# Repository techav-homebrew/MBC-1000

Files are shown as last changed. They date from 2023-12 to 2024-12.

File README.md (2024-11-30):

# MBC-1000
Reverse-engineering notes &amp; documentation of the Sanyo MBC-1000 computer

## Jumpers

There are four undocumented jumpers on the board. 

- JP1
  - Open by default.
- JP2
  - Open by default.
- JP3
  - Bridged by default. Connects ROM pin 21 to Vcc.
- JP4
  - Open by default. Connects ROM pin 21 to buffered A11 signal. 
- JP5
  - Bridged by default. 

If the trace shorting JP3 is cut and a jumper inserted into JP4, then the board should support a 2732 (4kB) EPROM in place of the 2716 (2kB) EPROM. The system memory map when the startup ROM overlay is enabled does support a 4kB EPROM.

## Address Map

The Spanish manual appendix IV seems to suggest that the startup overlay is disabled when the system addresses an OP code at a memory address above `$8000`. 

### Startup Memory Space Map

| Address | Function |
| :--- | :--- |
| `$0000 - $07ff` | First 2716 Boot ROM | 
| `$0800 - $0fff` | Second 2716 / First 2732 |
| `$1000 - $7fff` | Allocated ROM Space | 
| `$8000 - $ffff` | Allocated RAM Space |

### Runtime Memory Space Map

| Address | Function | 
| :--- | :---: |
| `$0000 - $ffff` | RAM |

### I/O Space Map

| Address | Function | IC |
| :--- | :--- | :--- |
| `$E0` | Parallel Printer Port Controls for RDY/BUSY | -- |
| `$E4` | Floppy Disk Controller | MB8876A |
| `$E8` | Parallel Port Interface | NEC D8255AC-5 |
| `$EC` | CRT Controller | HD46505SP-2 (68B45) |
| `$F0 - $F4` | Character Generator | -- |
| `$F8 - $FC` | Video RAM for Screen | -- |

A disassembled BIOS has IO calls to devices in the `$C0 - $C4` range in some of the disk read & write functions. The motherboard IO devices are decoded by a 74LS138 enabled when A7, A6, and A5 are all high, so a device on `$C0` would not be selected by that chip. The serial expansion card can only be configured at `$A0`, `$A8`, `$B0`, or `$B8`, so it's not what is being addressed here either. The manual only references the on-board peripherals in the `$E0 - $F0` range. So far I have not been able to trace out anything on the motherboard that would be selected for IO addresses `$C0 - $C4`

#### I/O Device Registers

##### PPI 8255

- `$E8` - PPI Port A
- `$E9` - PPI Port B
- `$EA` - PPI Port C
- `$EB` - PPI Control Register

##### FDC 8879

- `$E4` - Status (RO) / Command (WO)
- `$E5` - Track
- `$E6` - Sector
- `$E7` - Data

##### CRTC 6845

- `$EC` - Address Register
- `$ED` - Settings Registers
- `$EE` - Light Pen Registers

## Floppy Drive Interface

MBC-1000 and its dual floppy expansion box, EFD-360, use YE Data YD-274 floppy drives. These are standard Shugart-interface double-sided double-density 5.25" drives.

The `HM` jumper is set on each drive, and drives are selected with the `DSx` jumpers (Drive A is `DS0`, Drive B is `DS1`, Drive C is `DS2`). The last drive in the chain (Drive A if EFD-360 not used, or Drive C at the top of the EFD-360 if used) must have the 150-Ohm terminating resistor block installed. 

Drives use standard 34-contact card edge connectors for data & control. The motherboard uses a corresponding latching 34-pin header. A Centronics CN36 connector is used for the external interface on both the computer and the expansion drive. Wires 35 & 36 on the CN36 are cut, leaving the remaining standard 34 ribbon cable wires.

BIOS has data tables for 8" drives, and contemporary advertisements listed an 8" drive option. Some advertisements & reviews also mentioned Winchester hard drive options. ( [CPM Review Nov 1982](https://ia802805.us.archive.org/23/items/198211CPMReview/198211%20CPM%20Review.pdf) ).

Since the computer uses standard Shugart interface for floppy drives, it is compatible with Gotek emulators without any additional hardware (tested using FlashFloppy firmware).

## Monitor

The monitor is an NEC green phosphor display, type number C1270P1H-ARG. Its analog drive board is labeled with the Sanyo logo and `PH 50-002` & `PH-50E`.

## Escape Codes

Appendix VI of the Spanish manual provides an escape code sequence for positioning the cursor on screen:

> Las coordenadas X e Y tienen un umbral de valor hexa 20. Por ejemplo, para poner el cursor en la posicion X = 6 e Y = 8: 1Bh (ESC), 3Dh (=) 28h (20h + 8), 26h (20h + 6). Es la secuencia que debe de enviarse a la consola.

Columns are numbered 0 on the left through 79 on the right, and rows are numbered 0 at the top through 24 at the bottom. The constant `$20` is added to the row and column for the escape sequence.

`$1B` (Escape), `$3D` (Equals), `$20+Y` (row number plus `$20`), `$20+X` (column number plus `$20`).

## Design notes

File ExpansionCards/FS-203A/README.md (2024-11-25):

The FS-203A is a serial expansion card produced by Sanyo for the MBC-1000. It has an Intel P8251A UART and an NEC D8235C Programmable Interval Timer. 

The exact function of the timer is not clear, but it appears to be used to provide a timeout interrupt signal. Timer OUT1 latches register B on IC15 (74LS74) to high (it can be reset by writing to a specific address). If the timer has latched the register high, and the UART has asserted its Sync/Break detect signal, then an interrupt will be generated (if globally enabled by IC15 register A).

The card runs at half the bus clock of the system. The card clock is wired to the UART CLK input and the Timer CLK0 input. Output of Timer 0 drives the clock for Timer 1, which is used for the interrupt circuit previously described.

The schematic included here has been reverse-engineered from a unit manufacturered ca. late 1982. A schematic was included as an appendix in some copies of the manual.

## Addressing
The card's base address is selected by JP1, which is driven by the A-block outputs of IC1 (74LS139). IC1 A-block is enabled by output 5 of IC8 (74LS42), which is asserted when Address bits 7-5 equal 5 (A[7:5]=$5). IC1 address signals 1A & 1B are wired to A3 & A4, respectively. This results in an selectable base address range of `$A0` through `$BF` for the card. 

The B-block of IC1 is enabled by J1 and addressed by A1 & A2. Output 2 of IC1 B-block is wired to the chip enable signal of the 8251. This results in a selectable base address for the 8251 UART of `$A4`, `$AC`, `$B4`, or `$BC`. Outputs 1 and 0 of IC1 B-block are used to select the 8235 Timer by way of two gates (gate B, with gate D inverting the output of gate B) of IC11 (74LS00). This results in a selectable base address for the 8235 Timer of `$A0`, `$A8`, `$B0`, or `$B8`.

Output 3 of IC1 B-block addresses a pair of registers which control interrupts from the card. Writing to this address will set register A of IC15 (74LS74), which is a global interrupt enable for the card. Reading this address will reset register B. Register B is clocked by Timer OUT1.

The 8251 UART Control/Data# signal is wired directly to A0. Similarly, the 8235 A0 & A1 signals are wired directly to A0 & A1. 

## Serial Bit Rate
Serial Transmit/Receive clock source is a 15.9744MHZ TTL oscillator. This clock is divided by 4 via IC16 (74LS161), and then divided by 13 via IC17 (74LS161). The resulting 307.2kHz clock is fed into IC18 (74LS393), which provides the 8 clock signals selectable by JP2. The clock selected by JP2 runs directly to the transmit (TxC) and receive (RxC) clock inputs on the 8251. The final serial bit rate is selected via programming the 8251 to divide the TxC/RxC rate by 1, 16, or 64. All this together provides a possible bit rate range from 307200bps through 37.5bps.

The manual lists available baud rates (p163) of 9600 throug 150, with jumper 8 (19200) as not used, which means the default drivers would be setting the UART to the 16x clock divider. There is another note on the same page regarding inserting an external serial clock, stating the external clock must be 16x the required output baud rate, which confirms this UART configuration. 

## Power
The card gets its +5V logic power and signal ground from the expansion bus connector. There is a separate 3-pin power connector which provides chassis ground, +12V, & -12V for the serial transmitters (IC6 & IC7).

One thing to note is that while the serial transmitters are connected to chassis ground, the DB25 serial port itself is connected to signal ground. Nothing else on the card is connected to chassis ground. 

## Jumper Settings

### JP1
JP1 selects the base I/O address for the card

| Jumper | Base I/O Address |
| :---:  | ---: |
| 1 | `$A0` |
| 2 | `$A8` |
| 3 | `$B0` |
| 4 | `$B8` |

### JP2
JP2 selects the baud rate. The default drivers configure the 8251 UART to use a 16x divisor for the clock, which would produce the values in the table below (these values are given in a table in the manual for the computer). It is possible to configure the UART with a 1x divisor, which would result in baud rate selections 16x faster what is listed in this chart. It is also possible to configure the UART with a 64x divisor, which would result in baud rate selections 4x slower than what is listed in this chart.

| Jumper | Buad Rate |
| :---: | ---: |
| 1 | 150 |
| 2 | 300 | 
| 3 | 600 | 
| 4 | 1200 |
| 5 | 2400 | 
| 6 | 4800 |
| 7 | 9600 |
| 8 | 19200\* |

\* the manual lists jumper 8 as not used

### JP3
JP3 allows for use of external transmit & receive clock signals. External clock signals should be 16x the required serial bit rate when using the default drivers. 

When using external clock signals, the transmit clock is received on pin 15 and the receive clock is received on pin 17 of the DB25 port.

| Jumper | Description |
| :---: | :--- |
| 1 | Use external transmit clock |
| 2 | Use internal transmit clock\* |
| 3 | Use external receive clock |
| 4 | Use internal transmit clock\* |

\* default selection is to use internal clocks for transmit & receive

### JP4 & JP5
JP4 and JP5 are listed in the manual as not used for this card, and they are not populated with headers. These jumpers are connected to the threshold control signals of IC12 and IC10, respectively. In normal operation, these signals should be left floating (SN75154 datasheet calls this 'fail-safe' operation). There are some very specific cases listed in the SN75154 datasheet where the the threshold inputs might be connected to the chip's VCC1 supply input. In this card design, both VCC1 & VCC2 are wired to +5V. Closing JP4 & JP5 would short the threshold inputs to +5V.

### Unlabeled Jumper
There is one unlabeled normally-open solder-bridge jumper which would connect DB25 pin 14 to ground. In RS232 specification, this is the secondary transmit signal. 

## DB25 Pinout

| Signal | Signal Name | Pin No. |
| :---:  | :---: | :---: |
| FG | Frame Ground | 1 |
| TxD | Send Data | 2 |
| RxD | Receive Data | 3 |
| RTS | Request to Send Data | 4 |
| CTS | Clear to Send Data | 5 |
| DTR | Data Terminal Ready  | 20 | 
| DSR | Data Set Ready | 6 |
| TxC | Send Data Carrier | 15 |
| RxC | Receive Data Carrier | 17 |
| SG | Signal Ground | 7 |

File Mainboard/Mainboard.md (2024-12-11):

These notes are from a Revision 4 main board.

## Parts List

### Primary ICs
- NEC D780C-1 Z80 CPU
  - A12
- Motorola M5K4164NP-15 (x8) 64kbit DRAM [main memory]
  - Board label indicates MB8264-20
  - C12, D12, E12, F12, C13, D13, E13, F13
- Fujitsu MB8516H EPROM (2716)
  - B9
- Hitachi HD46505SP-2 CRT Controller (68B45)
  - Board label indicates HD46505-1
  - D9
- Hitachi HM6116P-3 (x2) 2kx8 SRAM [video memory]
  - F8, F6
- Fujitsu MB8876A Floppy Controller
  - D3
- NEC D8255AC-5 Programmable Peripheral Interface
  - F2

### Logic ICs
- 16MHz TTL Oscillator
  - G3
- 74LS32 (x3)
  - G12, D11, C9
- 74LS367 (x3)
  - A11, B11, A10
- 74157 (x6)
  - C11, C10, F9
- 74LS04 (x3)
  - E11, C5, G4
- 74LS00 (x4)
  - F11, E10, C6, C4
- 74LS74 (x4)
  - G11, G9, B2, D1
- 74LS10 (x2)
  - D10, A3
- 74LS02 (x3)
  - F10, C8, B3
- MC14584
  - G10
- 74LS244 (x4)
  - B8, B7, D7, D4
- 74LS107 
  - C7
- 74LS374
  - E7
- 74LS157 (x3)
  - D8, E8, F7, D6, E6
- 74LS138
  - B6
- 74LS245 (x2)
  - B5, D5
- 74LS30
  - E5
- 74128
  - B4
- 74LS161 (x2)
  - E4, C3
- 74LS166
  - F4
- 74LS14 (x2)
  - F3, D2
- 74LS221 (x2)
  - A2, C2
- 74LS123
  - E2
- 7416
  - B1
- 74145
  - C1
- 7407 (x2)
  - E1, G1
- JRC4558C
  - A1
- 75452B
  - C0

### Passive Components
Each IC has a 100nF 80%-20% (204Z) ceramic disk capacitor for decoupling. These are not labeled. 
There are two 47uF 16V axial electrolytic capacitors near the power supply connector. These are not labeled either. 

#### Resistors

| Position | Code | Value |
| --- | --- | ---: |
| R1 | SIP resistor pack, 9X102J | |
| R2 | SIP resistor pack, 9X102J | |
| R5 | brown-black-red-gold | 1k Ω 5% |
| R6 | green-blue-brown-gold |  560 Ω 5% |
| R7 | brown-black-orange-gold |  10k Ω 5% |
| R8 | brown-black-orange-gold |  10k Ω 5% |
| R9 | orange-orange-red-gold | 3.3k Ω 5% |
| R10 | brown-green-brown-gold |  150 Ω 5% |
| R11 | brown-green-brown-gold |  150 Ω 5% |
| R12 | brown-green-brown-gold |  150 Ω 5% |
| R13 | brown-green-brown-gold |  150 Ω 5% |
| R14 | brown-brown-black-red-brown |  11k Ω 1% |
| R15 | brown-black-black-yellow-brown  | 1M Ω 1% |
| R16 | grey-red-red-gold | 8.2k Ω 5% |
| R17 | white-brown-black-brown-brown | 9.1k Ω 1% |
| R18 | white-brown-black-brown-brown | 9.1k Ω 1% |
| R19 | brown-black-black-yellow-brown  | 1M Ω 1% |
| R20 | brown-black-black-yellow-brown  | 1M Ω 1% |
| R21 | brown-black-black-yellow-brown  | 1M Ω 1% |
| R22 | yellow-violet-red-gold | 4.7k Ω 5% |
| R23 | yellow-violet-black-brown-brown | 9.1k Ω 1% |
| R24 | brown-black-red-gold | 1k Ω 5% |
| R27 | orange-orange-brown-gold |  330 Ω 5% |
| R28 | brown-red-orange-gold |  12k Ω 5% |
| R29 | orange-orange-brown-gold |  330 Ω 5% |
| R30 | brown-black-red-gold | 1k Ω 5% |
| R31 | yellow-violet-red-gold | 4.7k Ω 5% |
| R32 | orange-orange-red-gold | 3.3k Ω 5% |
| R33 | orange-orange-red-gold | 3.3k Ω 5% |
| R34 | orange-orange-red-gold | 3.3k Ω 5% |
| R35 | brown-black-orange-gold |  10k Ω 5% |
| R36 | orange-orange-red-gold | 3.3k Ω 5% |
| R37 | brown-black-yellow-gold | 100k Ω 5% |
| R38 | brown-black-red-gold | 1k Ω 5% |
| R39 | brown-black-red-gold | 1k Ω 5% |
| R40 | brown-black-red-gold | 1k Ω 5% |
| R41 | red-red-brown-gold |  220 Ω 5% |
| R42 | orange-orange-red-gold | 3.3k Ω 5% |
| R43 | orange-orange-red-gold | 3.3k Ω 5% |
| R44 | orange-orange-red-gold | 3.3k Ω 5% |
| R45 | orange-orange-red-gold | 3.3k Ω 5% |
| R46 | brown-black-red-gold | 1k Ω 5% |
| M16A | 10K DIP resistor pack | |
| VR | 502 variable resistor | |

#### Capacitors
- C1 0.47u 35V Tantalum
- C2, C3, C4, C5, C6, C7, C8, C9 102 Ceramic
- C11 P102J
- C12 0.1u 35V Tantalum
- C13 33
- C14 0680J
- C15 2000J
- C16 0680J
- C17 0680J
- C20 10u 16V Electrolytic
- C21 103K Ceramic
- C22 10u 16V Tantalum
- C23 47u 16V Tantalum
- C24 271
- C25 472K
- C26 271
- C27 271
- C28 271
- C29 271
- C30 101

#### Inductors
- L1, L2, L3, L4, L5, L6, L7, L8 100
- L9, L10 180 

#### Misc
- Q1 D1111 2G
- D1, D2, D3, D4, D5 unlabeled, look like 1N4148
- Buzzer (piezo)
- J1 16-pin right-angle header (keyboard)
- J2 (printer)
- J3 (power)
- J4 34-pin header with latches (floppy)
- J5 (video)
- J6 50-pin header with latches (extension bus)
- FG frame ground connector

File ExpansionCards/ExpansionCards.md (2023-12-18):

# Expansion Cards

## Expansion Connector Pinout
Expansion cards share a 50-pin bus connected via ribbon cable. Signals are buffered on the main board with B5 (74LS245), B7 (74LS244), and B8 (74LS244). 

| Row 1 Pin | Signal | Row 2 Pin | Signal | 
| --- | --- | --- | --- |
|  1 | D0 |  2 | Ground |
|  3 | D1 |  4 | Ground |
|  5 | D2 |  6 | Ground |
|  7 | D3 |  8 | Ground |
|  9 | D4 | 10 | Ground | 
| 11 | D5 | 12 | Ground | 
| 13 | D6 | 14 | Ground |
| 15 | D7 | 16 | Ground |
| 17 | WR# | 18 | Ground |
| 19 | RD# | 20 | Ground |
| 21 | A0 | 22 | Ground | 
| 23 | A1 | 24 | Ground | 
| 25 | A2 | 26 | Ground |
| 27 | A3 | 28 | Ground |
| 29 | A4 | 30 | Ground |
| 31 | A5 | 32 | Ground |
| 33 | A6 | 34 | Ground |
| 35 | A7 | 36 | Ground |
| 37 | RESET# | 38 | Ground |
| 39 | CLOCK  | 40 | Ground |
| 41 | INT# | 42 | Ground | 
| 43 | NMI# | 44 | Ground |
| 45 | IORQ#  | 46 | +5V |
| 47 | M1# | 48 | +5V | 
| 49 | [NC] | 50 | +5V |

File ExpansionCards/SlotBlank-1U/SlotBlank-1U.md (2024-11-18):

MBC-1000 supports up to 4 expansion cards. Cards not present will need a blank slot cover. Each slot is 17mm wide and 73.3mm tall. Slot covers are made from L-shaped powder-coated or painted steel. 

The FreeCAD and exported files were created from measuring an original part. It should be possible to fabircate or 3D print the slot cover from these files, but they are untested.

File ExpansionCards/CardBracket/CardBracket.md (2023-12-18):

Expansion cards need a small bracket to secure the card to the chassis. The original bracket is made out of bent steel. It is secured to the card using an M3 machine screw, and attaches to the chassis using a Nifco-Japan Niflatch fastener (it looks like part number `2012`)

The FreeCAD and exported files were created from measuring an original part. It should be possible to machine or 3D print the bracket from these files, but they are untested.

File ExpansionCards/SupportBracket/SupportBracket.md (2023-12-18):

The MBC-1000 chassis has holes for a card support bracket for each slot, but the brackets may not be populated for any cards not purchased with the computer. Original part number was Kal-am `051-44-001-41`. 

The FreeCAD & exported step file were created from measuring an original part. It should be possible to 3D print the bracket from these files, but they are untested.

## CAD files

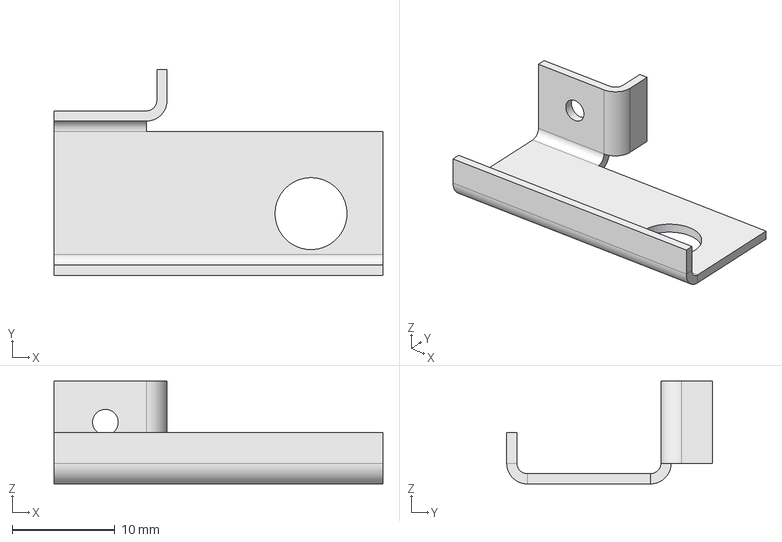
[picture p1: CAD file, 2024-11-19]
ExpansionCards/CardBracket/MBC1000_CardBracket-Body.step
32.0 x 20.0 x 10.0 mm

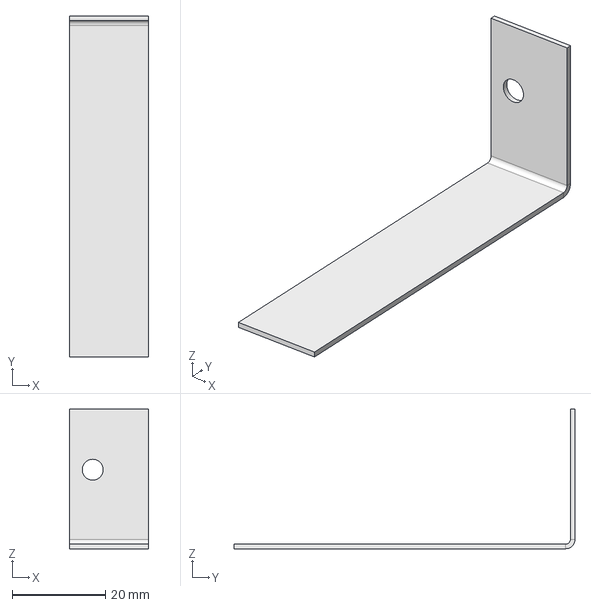
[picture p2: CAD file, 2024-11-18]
ExpansionCards/SlotBlank-1U/SlotBlank-1U.step
17.0 x 73.3 x 30.0 mm

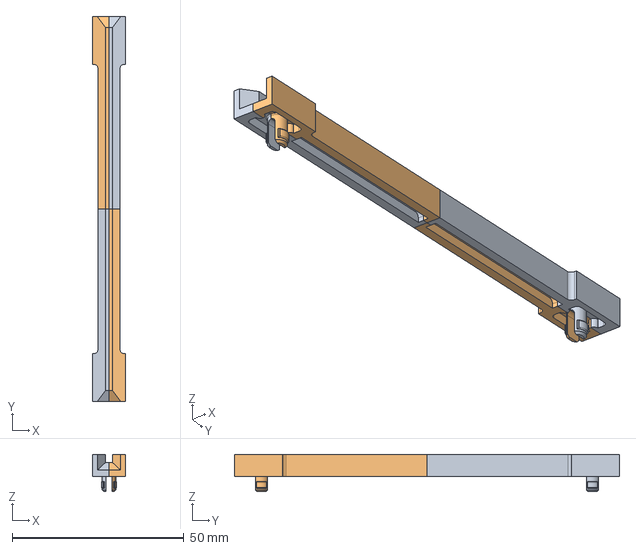
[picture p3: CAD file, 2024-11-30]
ExpansionCards/SupportBracket/Kel-am_051-44-001-41_JLC.step
9.60 x 112.0 x 10.9 mm

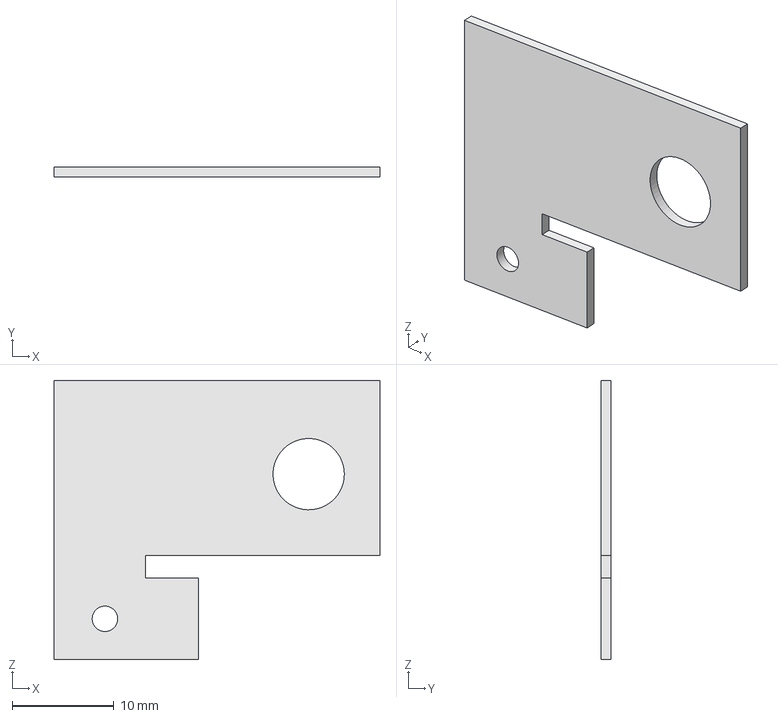
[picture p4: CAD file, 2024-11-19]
ExpansionCards/CardBracket/MBC1000_CardBracket.FCStd
32.0 x 1.00 x 27.4 mm

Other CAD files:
ExpansionCards/SupportBracket/Kel-am_051-44-001-41-Compound.step
ExpansionCards/SupportBracket/Kel-am_051-44-001-41.FCStd
ExpansionCards/SlotBlank-1U/SlotBlank-1U.FCStd
ExpansionCards/SupportBracket/Kel-am_051-44-001-41_JLC.FCStd

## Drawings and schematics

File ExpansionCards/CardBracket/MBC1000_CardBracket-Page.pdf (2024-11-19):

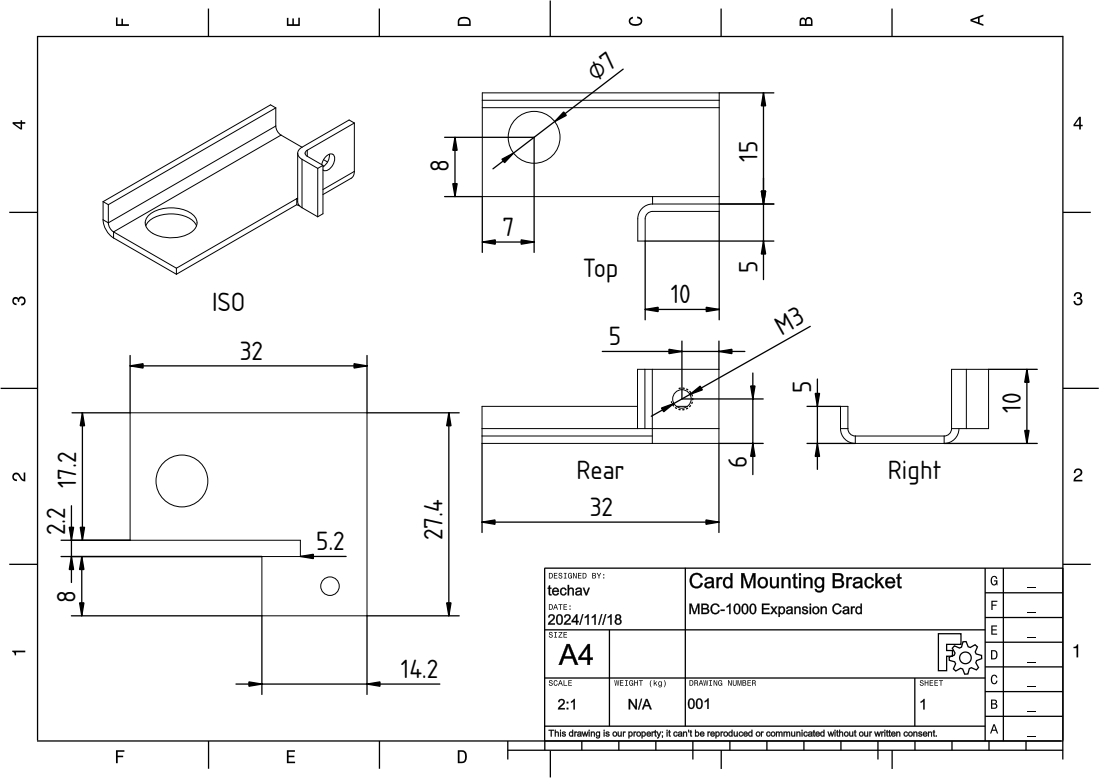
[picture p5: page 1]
Rig; 5 ISO 27.4 14.2 32 5.2

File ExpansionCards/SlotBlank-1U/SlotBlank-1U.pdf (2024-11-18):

# ht 73.3 Top

ar 17

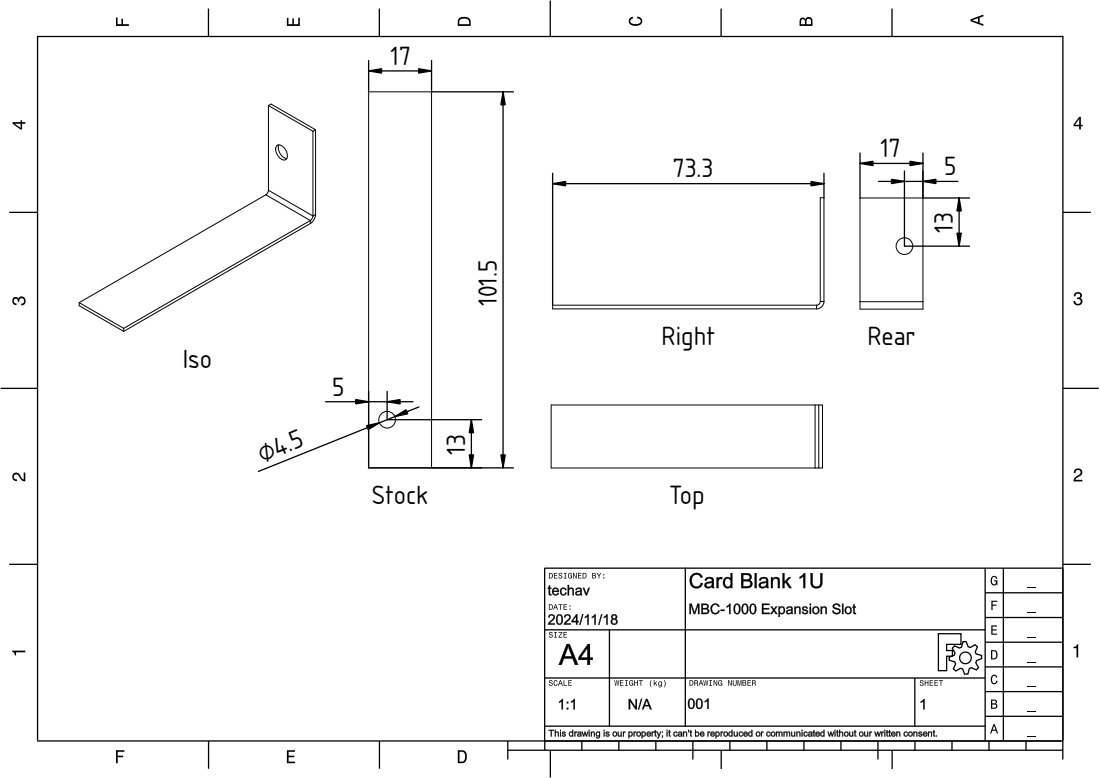
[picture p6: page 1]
Stock; Rig

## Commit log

2023-12-18 Initial notes upload
    [Kel-am_051-44-001-41-Compound.step, Kel-am_051-44-001-41.FCStd, MBC1000_CardBracket-Body.step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]
2023-12-19 Replace FreeCAD PCB drawing with more detailed KiCAD template
    [MBC100_PCB.FCStd, MBC100_PCB_Template.kicad_pcb]
2023-12-20 Reverse-engineered schematic for FS-203A serial card
    [FS203A_Reverse.kicad_pcb, FS203A_Reverse.kicad_sch]
2024-11-18 Add expansion slot blank cover
    [SlotBlank-1U.FCStd, SlotBlank-1U.step]
2024-11-19 Rebuild card bracket to clarify bends
    [MBC1000_CardBracket-Body.step, MBC1000_CardBracket.FCStd]
2024-11-21 start mainboard schematic reverse engineer
    [MBC-1000_Mainboard.kicad_pcb, MBC-1000_Mainboard.kicad_sch]
2024-11-22 Start mainboard RAM schematic
    [MBC-1000_Mainboard.kicad_sch]
2024-11-23 Continue mainboard logic schematic
    [MBC-1000_Mainboard.kicad_sch]
2024-11-24 Mainboard jumpers, keyboard IO, printer IO
    [MBC-1000_Mainboard.kicad_sch]
2024-11-24 Mainboard VRAM & CRAM addressing
    [MBC-1000_Mainboard.kicad_sch]
2024-11-25 add info on disks, monitor, serial, keyboard pinout
    [MBC-1000_Mainboard.kicad_sch]
2024-11-30 Modify card support bracket for JLC3DP
    [Kel-am_051-44-001-41_JLC.FCStd, Kel-am_051-44-001-41_JLC.step]
2024-11-30 Add remaining IC & connector footprints to mainboard schematic
    [MBC-1000_Mainboard.kicad_sch]
2024-11-30 Mainboard clock & expansion bus
    [MBC-1000_Mainboard.kicad_sch]
2024-12-02 Mainboard floppy interface, Video memory addressing
    [MBC-1000_Mainboard.kicad_sch]
2024-12-11 Translate resistor codes into values
2024-12-15 Mainboard video output logic
    [MBC-1000_Mainboard.kicad_sch]
2025-01-14 Mainboard reversing continued
    [MBC-1000_Mainboard.kicad_sch]
2025-01-16 Motherboard trace out final IC signals
    [MBC-1000_Mainboard.kicad_sch]
